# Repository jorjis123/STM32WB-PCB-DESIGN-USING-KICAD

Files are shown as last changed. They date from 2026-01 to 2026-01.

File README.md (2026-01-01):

**STM32 Bluetooth Development Board**

A compact, versatile development platform based on the STM32 architecture, designed for Bluetooth Low Energy (BLE) applications and rapid prototyping. This board integrates power management, USB connectivity, and RF capabilities in a small form factor.

**🚀 Key Features**

Microcontroller: Integrated STM32 MCU with Bluetooth support (QFN package).

Connectivity: * USB-C Port: For power and data communication.

UART Header (J4): Dedicated serial interface for debugging or external modules.

SWD Interface (J2): Tag-Connect or pogo-pin footprint for high-speed programming and debugging.

RF Design: * Onboard RF circuitry with an integrated filter (FLT1).

U.FL Connector (J1): For external antenna connection.

**User Interface:**

BOOT Button (SW1): Easy access to bootloader mode for firmware flashing.

Status LEDs for power and user-defined signals.

Power Management: Onboard LDO regulators (U2, U3) to manage USB power delivery.

**🛠 Hardware Overview**
Component Map
Reference	Description
U1	    STM32 Bluetooth MCU
USB	    USB Type-C Connector
J1	    RF U.FL Antenna Connector
J2	    SWD Programming Header (Footprint)
J4	    UART Communication Header
SW1	    Bootloader / User Switch
X1 / X2	High and Low-speed Crystal Oscillators

Programming:
The board can be programmed via the SWD (Serial Wire Debug) port using an ST-LINK/V2 or V3. To enter the built-in system bootloader for USB programming, hold the BOOT button while powering on or resetting the device.

**3D VIEW**



**PCB ROUTING**



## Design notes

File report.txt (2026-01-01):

Changed footprint J4 from 'Connector_Phoenix_MC:PhoenixContact_MCV_1,5_4-GF-3.5_1x04_P3.50mm_Vertical_ThreadedFlange_MountHole' to 'Connector_Molex:Molex_PicoBlade_53048-0410_1x04_P1.25mm_Horizontal': : OK

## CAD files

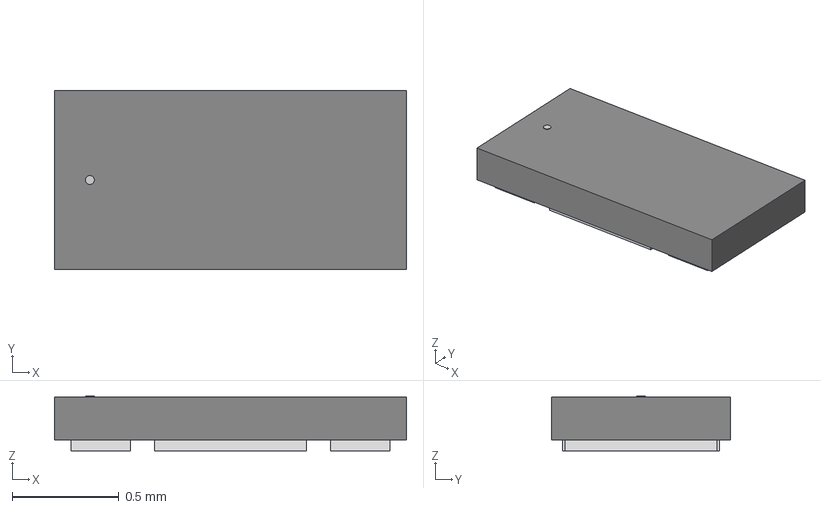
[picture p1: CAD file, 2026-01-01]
DLF-4_1P6X0P8.step
1.65 x 0.838 x 0.257 mm

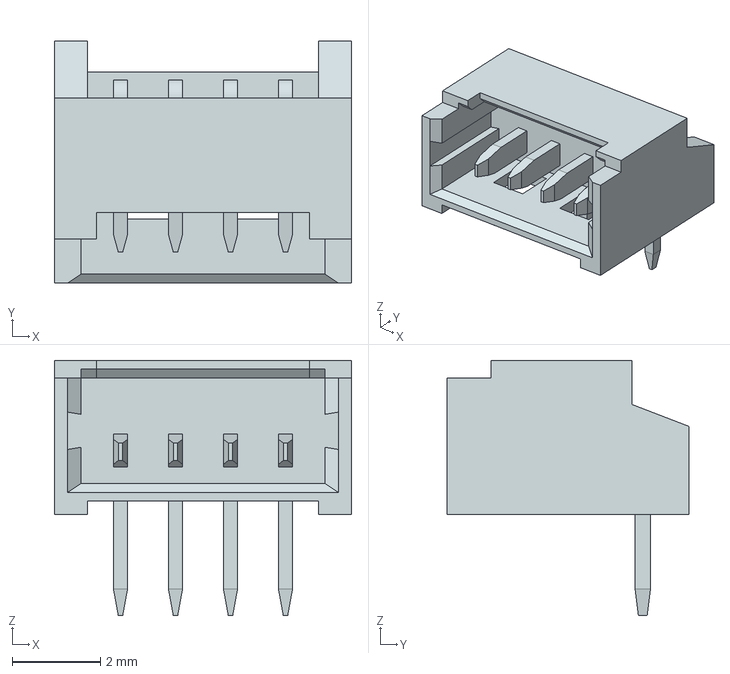
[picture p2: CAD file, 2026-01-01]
0530480410.stp
6.75 x 5.50 x 5.80 mm

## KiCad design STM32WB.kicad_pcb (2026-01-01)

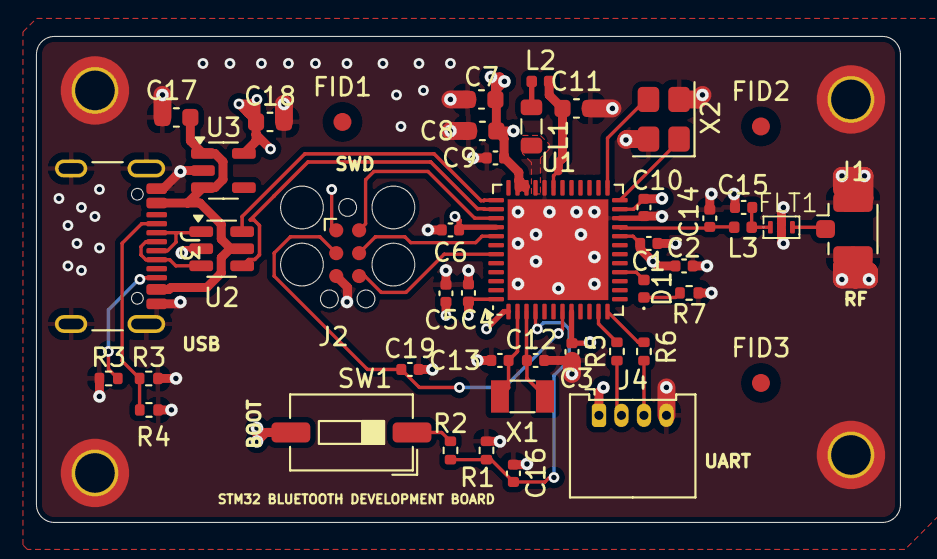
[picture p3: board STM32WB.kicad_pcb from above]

Board: 4 copper layers, 48.0 x 27.0 mm, 49 parts (0 on the bottom side), 30 nets.

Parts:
C1, C2, C3, C4, C5, C6, C9, C10, C16, C19: 100n; C_0402_1005Metric
C7, C8, C11, C17, C18: 4u7; C_0603_1608Metric
C12, C13: 10p; C_0402_1005Metric
C14: 0p8; C_0402_1005Metric
C15: 0p3; C_0402_1005Metric
D1: LD274; LED_0402_1005Metric
FID1, FID2, FID3: Fiducial; Fiducial_1mm_Mask2mm
FLT1: DLF162500LT-5028A1
H1, H2, H3, H4: MountingHole_Pad; MountingHole_2.2mm_M2_ISO14580_Pad_TopOnly
J1: Conn_Coaxial; U.FL_Hirose_U.FL-R-SMT-1_Vertical
J2: TC2030; Tag-Connect_TC2030-IDC-FP_2x03_P1.27mm_Vertical
J3: USB_C_Receptacle_USB2.0_16P; USB_C_Receptacle_GCT_USB4105-xx-A_16P_TopMnt_Horizontal
J4: Conn_01x04_Pin; Molex_PicoBlade_53048-0410_1x04_P1.25mm_Horizontal
L1: 10n; L_0805_2012Metric
L2: 10u; L_0402_1005Metric
L3: 2n7; L_0402_1005Metric
R1, R3, R3#2, R4: 5k1; R_0402_1005Metric
R2, R5, R6, R7: 220R; R_0402_1005Metric
SW1: SW_Push; SW_DIP_SPSTx01_Slide_6.7x4.1mm_W6.73mm_P2.54mm_LowProfile_J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
U1: STM32WB55CCU6; QFN-48-1EP_7x7mm_P0.5mm_EP5.6x5.6mm
U2: USBLC6-2SC6; SOT-23-6
U3: MIC5365-3.3YD5; TSOT-23-5
X1: 32kHz768; Crystal_SMD_3215-2Pin_3.2x1.5mm
X2: 32MHz; Crystal_SMD_3225-4Pin_3.2x2.5mm

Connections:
+3V3: C1.1, C2.1, C3.1, C4.1, C5.1, C6.1, C7.1, C8.1, C9.1, C10.1, C18.1, J2.1 (VCC), J4.1, SW1.2, U1.1 (VBAT), U1.8 (VDDA), U1.20 (VDD), U1.23 (VDDRF), U1.34 (VDDSMPS), U1.35 (VDD), U1.40 (VDDUSB), U1.48 (VDD), U3.5 (VOUT)
+5V: C17.1, J3.A4 (VBUS), J3.A9 (VBUS), J3.B4 (VBUS), J3.B9 (VBUS), U2.5 (VBUS), U3.1 (VIN), U3.3 (EN)
/BOOT0: C16.1, R1.1, R2.1, U1.4 (PH3)
/LED_a: D1.2 (A), U1.16 (PA7)
/RF: C14.1, L3.1, U1.21 (RF1)
/RF_ANT: FLT1.3 (OUT), J1.1 (In)
/RF_MATCH: C15.1, FLT1.1 (IN), L3.2
/SMPS_FB: C11.1, L2.2, U1.31 (VFBSMPS)
/SMPS_LX: L1.1, U1.33 (VLXSMPS)
/SWD_CLK: J2.4 (SWCLK), U1.41 (PA14)
/SWD_DIO: J2.2 (SWDIO), U1.39 (PA13)
/SWD_NRST: C19.1, J2.3 (~RESET), U1.7 (NRST)
/SWD_TRC: J2.6 (SWO), U1.43 (PB3)
/UART_RX: R6.2, U1.12 (PA3)
/UART_RXC: J4.3, R6.1
/UART_TX: R5.2, U1.11 (PA2)
/UART_TXC: J4.2, R5.1
/USB_CC1: J3.A5 (CC1), R3.1, R4.1
/USB_CC2: J3.B5 (CC2), R3#2.2
/USB_D+: J3.A6 (D+), J3.B6 (D+), U1.38 (PA12), U2.3 (I/O2), U2.4 (I/O2)
/USB_D-: U1.37 (PA11), U2.6 (I/O1)
GND: C1.2, C2.2, C3.2, C4.2, C5.2, C6.2, C7.2, C8.2, C9.2, C10.2, C11.2, C12.2, C13.2, C14.2, C15.2, C16.2, C17.2, C18.2, C19.2, FLT1.2 (GND), FLT1.4 (GND), H1.1, H2.1, H3.1, H4.1, J1.2 (Ext), J2.5 (GND), J3.A1 (GND), J3.A12 (GND), J3.B1 (GND), J3.B12 (GND), J3.S1 (SHIELD), J4.4, R1.2, R3.2, R3#2.1, R4.2, R7.1, U1.22 (VSSRF), U1.32 (VSSSMPS), U1.49 (VSS), U2.2 (GND), U3.2 (GND), X2.2, X2.4
unnamed: D1.1 (K), R7.2
unnamed: J3.A7 (D-), J3.B7 (D-), U2.1 (I/O1)
unnamed: L1.2, L2.1
unnamed: R2.2, SW1.1
unnamed: U1.25 (OSC_IN), X2.3
unnamed: U1.24 (OSC_OUT), X2.1
unnamed: C13.1, U1.2 (PC14), X1.2
unnamed: C12.1, U1.3 (PC15), X1.1
